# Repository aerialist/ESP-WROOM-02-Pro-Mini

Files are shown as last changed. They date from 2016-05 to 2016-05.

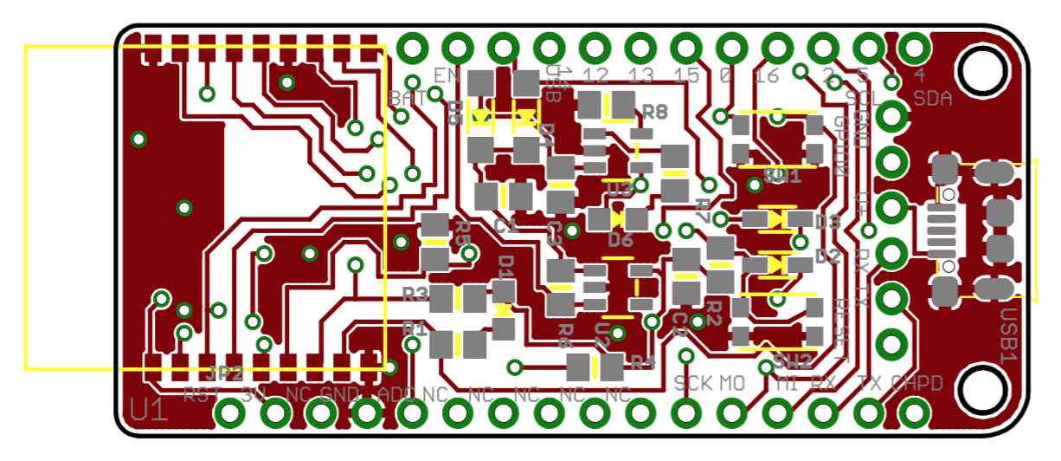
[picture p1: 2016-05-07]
ESP-WROOM-02-Pro-Mini_v1.1_layoutA.png

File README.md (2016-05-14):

# ESP-WROOM-02-Pro-Mini
This is yet another ESP-WROOM-02 breakout.

Warning: This hasn't been fabricated or tested yet.

Design intentions are:

* Use ESP-WROOM-02 so that it can be used in Japan with TELEC cetification.
* It would fit to Adafruit Feather Wing product line.
* Remove serial-to-USB conversion circuit to reduce cost and save space.
* Keep uUSB connector for powering the device.
* Battery connector is optional and moved to the backside to save space.
* LiPo charging circuit is optional.

ESP-WROOM-02 eagle library is taken from
https://github.com/ikesato/eagle-libraries/blob/master/lbr/esp-wroom-02.lbr

The design is derived from Adafruit-Huzzah-ESP8266-Basic-Breakout-PCB and Adafruit-Feather-ESP8266-HUZZAH-PCB. Please find the copy of original readme attached below.

# Adafruit-Huzzah-ESP8266-Basic-Breakout-PCB
PCB files for Adafruit Huzzah ESP8266 Basic Breakout

Format is EagleCAD schematic and board layout

For more details, check out the product page at

-----> http://www.adafruit.com/products/2471

Adafruit invests time and resources providing this open source design, 
please support Adafruit and open-source hardware by purchasing 
products from Adafruit!

Designed by Adafruit Industries.  
Creative Commons Attribution, Share-Alike license, check license.txt for more information
All text above must be included in any redistribution

# Adafruit-Feather-ESP8266-HUZZAH-PCB
PCB files for the Adafruit Feather ESP8266 HUZZAH

Format is EagleCAD schematic and board layout

For more details, check out the product page at

  * https://www.adafruit.com/product/2821

Adafruit invests time and resources providing this open source design, 
please support Adafruit and open-source hardware by purchasing 
products from Adafruit!

Designed by Adafruit Industries.  
Creative Commons Attribution, Share-Alike license, check license.txt for more information
All text above must be included in any redistribution

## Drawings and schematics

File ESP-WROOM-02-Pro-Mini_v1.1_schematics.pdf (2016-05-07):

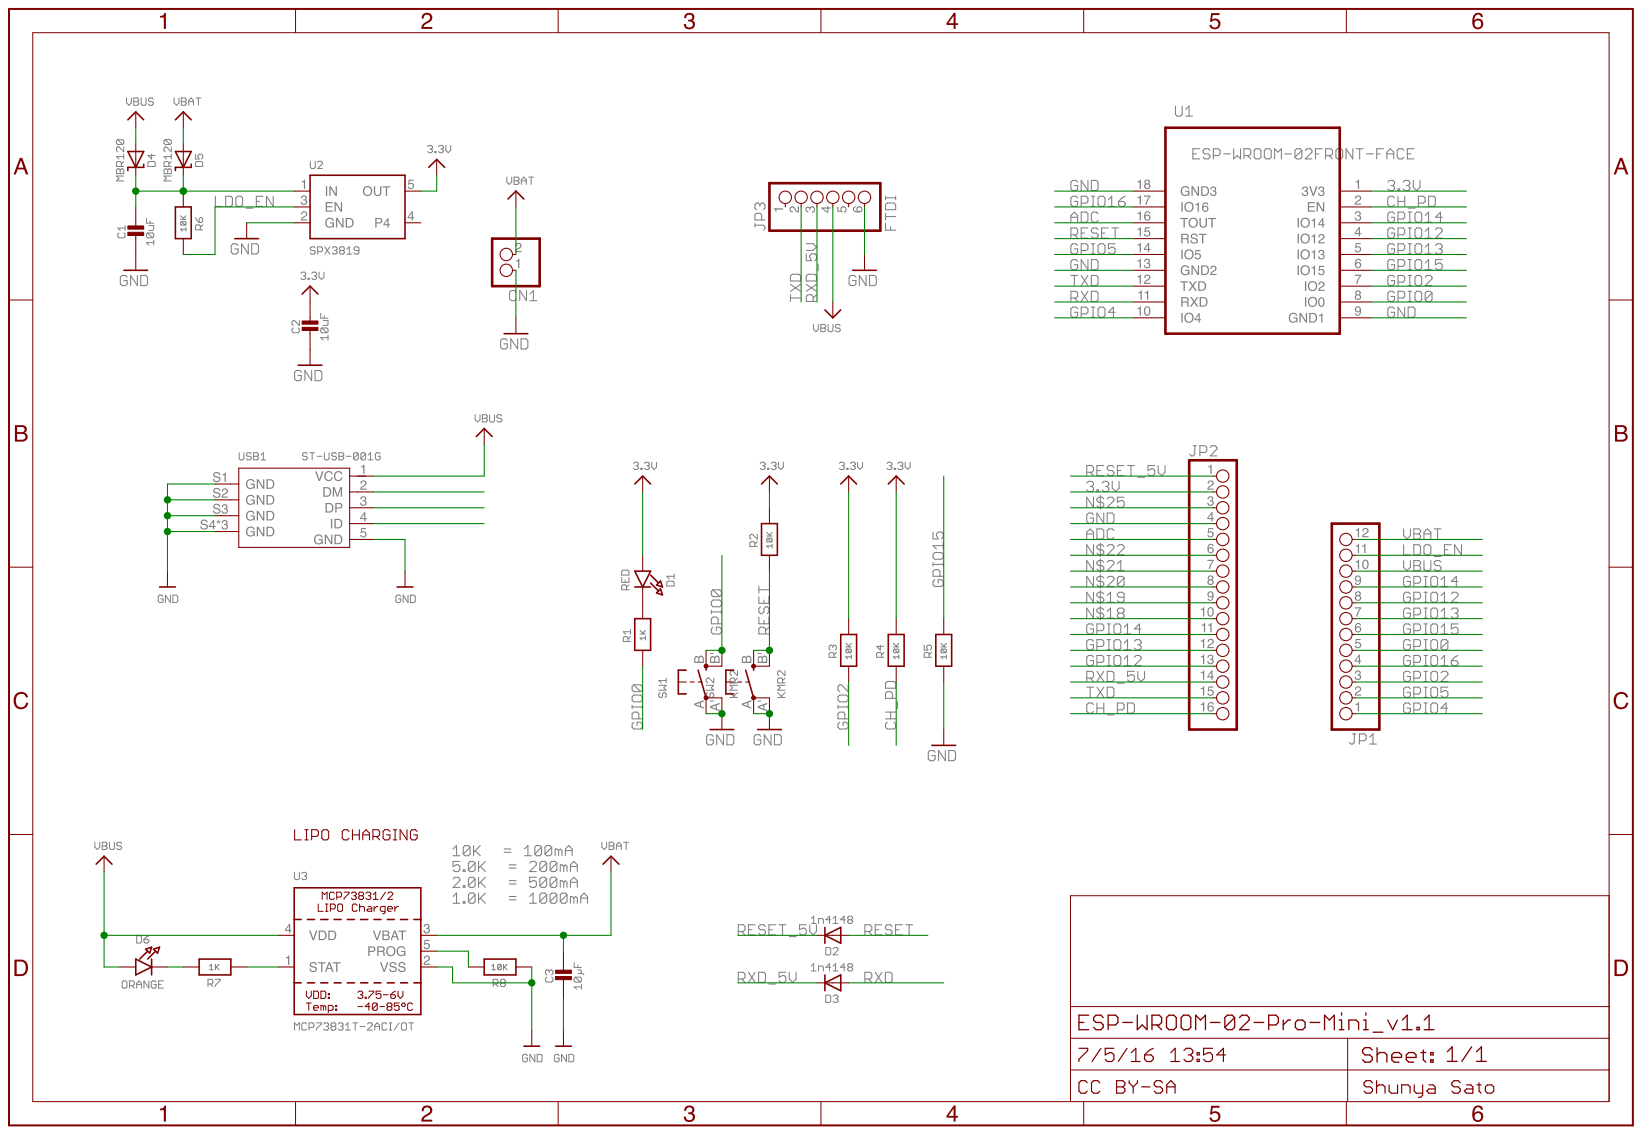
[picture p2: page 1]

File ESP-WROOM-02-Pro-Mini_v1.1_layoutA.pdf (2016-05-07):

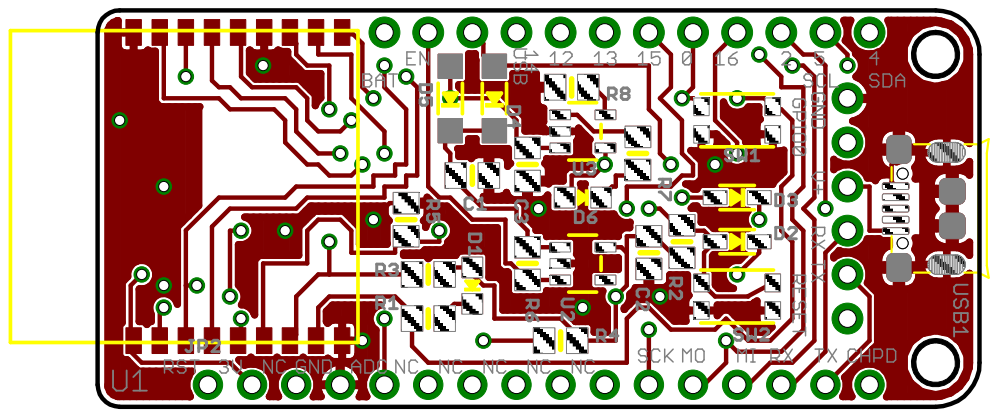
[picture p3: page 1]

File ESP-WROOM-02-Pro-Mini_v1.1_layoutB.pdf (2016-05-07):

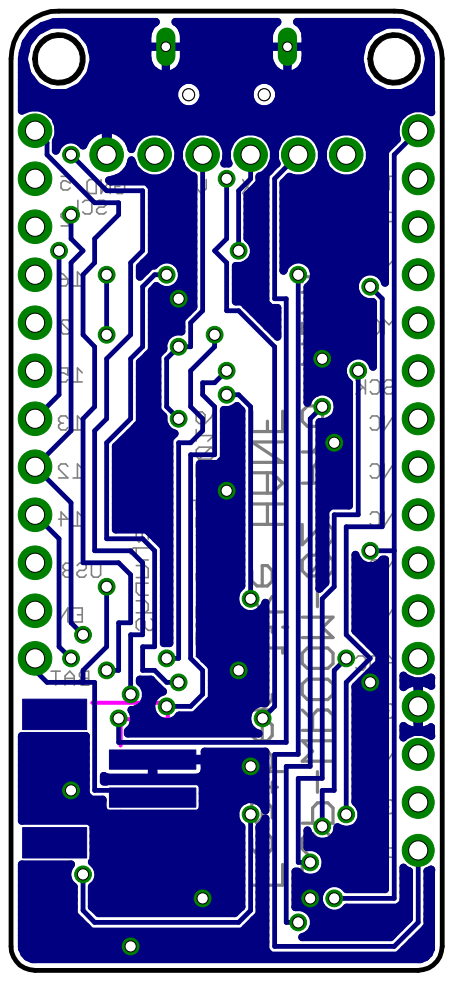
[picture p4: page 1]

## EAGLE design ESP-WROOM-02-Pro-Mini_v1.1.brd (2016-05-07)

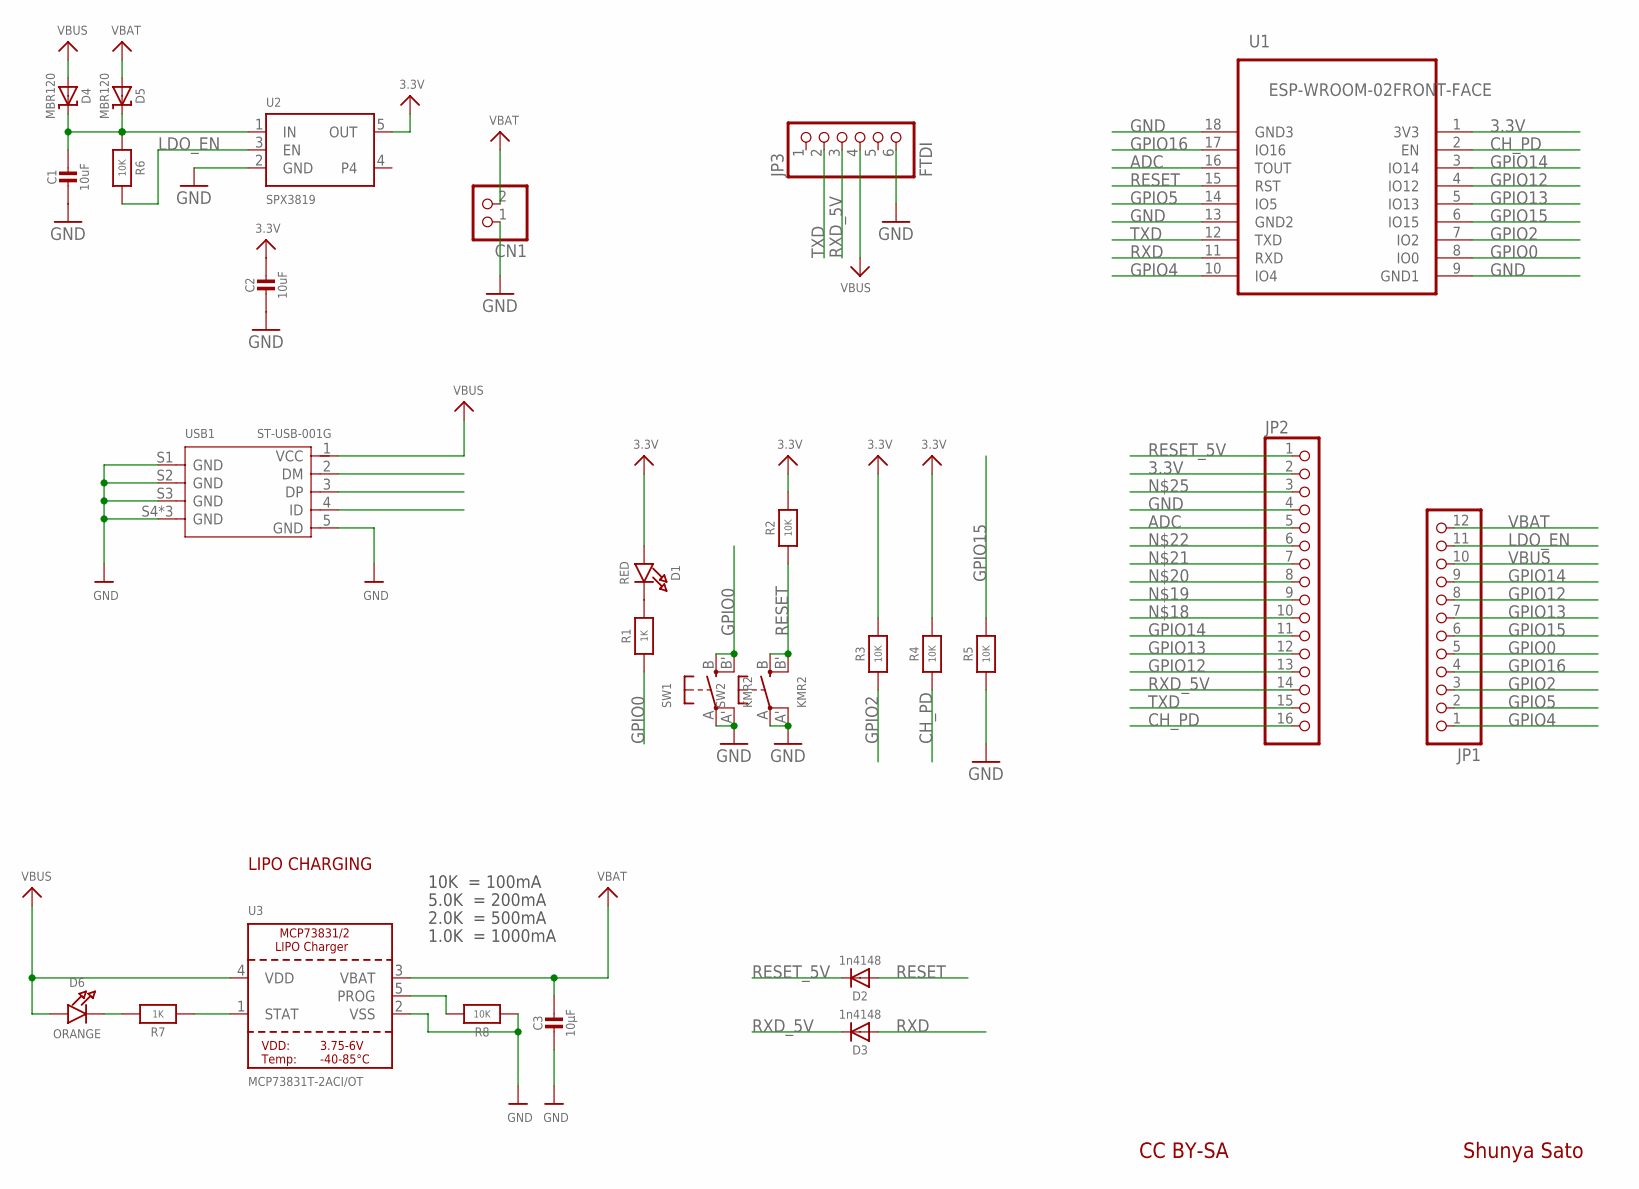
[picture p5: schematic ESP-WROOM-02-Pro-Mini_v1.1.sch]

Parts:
C1, C2: 10uF; 0805-NO
C3: 10µF; 0805-NO
CN1: JST_2PIN; JSTPH2
D1: RED; CHIPLED_0805_NOOUTLINE
D2, D3: 1n4148; SOD-323
D4, D5: MBR120; SOD-123
D6: ORANGE; CHIPLED_0805_NOOUTLINE
JP1: PINHD-1X12-CB; 1X12-CB
JP2: HEADER-1X16ROUND; 1X16_ROUND
JP3: FTDI; 1X06_ROUND_70
R1, R7: 1K; 0805-NO
R2, R3, R4, R5, R6, R8: 10K; 0805-NO
SW1, SW2: KMR2; BTN_KMR2_4.6X2.8
U1: ESP-WROOM-02FRONT-FACE; FRONT-FACE
U2: SPX3819; SOT23-5
U3: MCP73831T-2ACI/OT; SOT23-5
USB1: ST-USB-001G; MICRO-USB5+4P-SMD-0.65-B

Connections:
3.3V: C2.1, D1.A, JP2.2, R2.2, R3.2, R4.2, U1.1 (3V3), U2.5 (OUT)
ADC: JP2.5, U1.16 (TOUT)
CH_PD: JP2.16, R4.1, U1.2 (EN)
GND: C1.2, C2.2, C3.2, CN1.1, JP2.4, JP3.6, R5.1, R8.1, SW1.A, SW1.A' (P1), SW2.A, SW2.A' (P1), U1.9 (GND1), U1.13 (GND2), U1.18 (GND3), U2.2 (GND), U3.2 (VSS), USB1.5 (GND), USB1.S1 (GND), USB1.S2 (GND), USB1.S3 (GND), USB1.S4 (GND), USB1.S5 (GND), USB1.S6 (GND)
GPIO0: JP1.5, R1.1, SW1.B (S), SW1.B' (S1), U1.8 (IO0)
GPIO2: JP1.3, R3.1, U1.7 (IO2)
GPIO4: JP1.1, U1.10 (IO4)
GPIO5: JP1.2, U1.14 (IO5)
GPIO12: JP1.8, JP2.13, U1.4 (IO12)
GPIO13: JP1.7, JP2.12, U1.5 (IO13)
GPIO14: JP1.9, JP2.11, U1.3 (IO14)
GPIO15: JP1.6, R5.2, U1.6 (IO15)
GPIO16: JP1.4, U1.17 (IO16)
LDO_EN: JP1.11, R6.2, U2.3 (EN)
unnamed: D6.C, R7.2
unnamed: R7.1, U3.1 (STAT)
unnamed: C1.1, D4.C, D5.C, R6.1, U2.1 (IN)
unnamed: D1.C, R1.2
unnamed: R8.2, U3.5 (PROG)
RESET: D2.A, R2.1, SW2.B (S), SW2.B' (S1), U1.15 (RST)
RESET_5V: D2.C, JP2.1
RXD: D3.A, U1.11 (RXD)
RXD_5V: D3.C, JP2.14, JP3.3
TXD: JP2.15, JP3.2, U1.12 (TXD)
VBAT: C3.1, CN1.2, D5.A, JP1.12, U3.3 (VBAT)
VBUS: D4.A, D6.A, JP1.10, JP3.4, U3.4 (VDD), USB1.1 (VCC)

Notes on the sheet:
10K = 100mA
5.0K = 200mA
2.0K = 500mA
1.0K = 1000mA
LIPO CHARGING
Shunya Sato
CC BY-SA

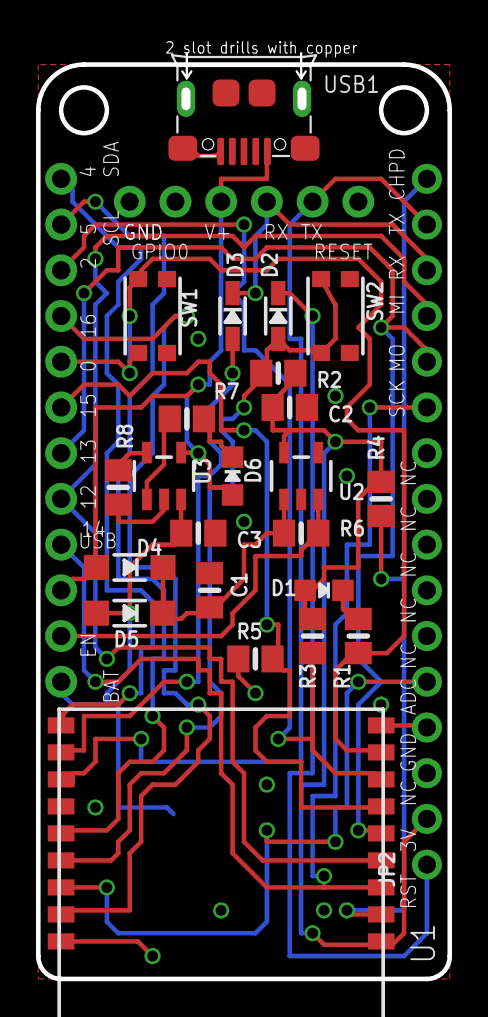
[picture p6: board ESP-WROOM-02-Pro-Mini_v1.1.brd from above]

Board: 2 copper layers, 22.9 x 51.4 mm, 27 parts (1 on the bottom side), 26 nets.

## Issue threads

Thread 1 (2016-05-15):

Make GND clearance area under antenna

aerialist, 2016-05-15:

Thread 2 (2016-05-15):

Define pads for WROOM02 in stensil

aerialist, 2016-05-15:
Currently the stencil doesn't include pads for ESP-WROOM-02...
Define them and send PR.

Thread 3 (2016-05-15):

Add NodeMCU style reset trick

aerialist, 2016-05-15:
Add a couple of transistors like in Adafruit Feather Huzzah

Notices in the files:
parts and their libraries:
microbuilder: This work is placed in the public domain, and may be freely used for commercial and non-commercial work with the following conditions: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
